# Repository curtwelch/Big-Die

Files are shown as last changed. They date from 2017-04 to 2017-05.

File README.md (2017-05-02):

# Readme

A Project to make a large 6" cube gambling die out of wood on a CNC router and out of plastic on a 3D Printer as a learning exercise.

Included here are the Fusion 360 CAD files, DXF files, and STL files.

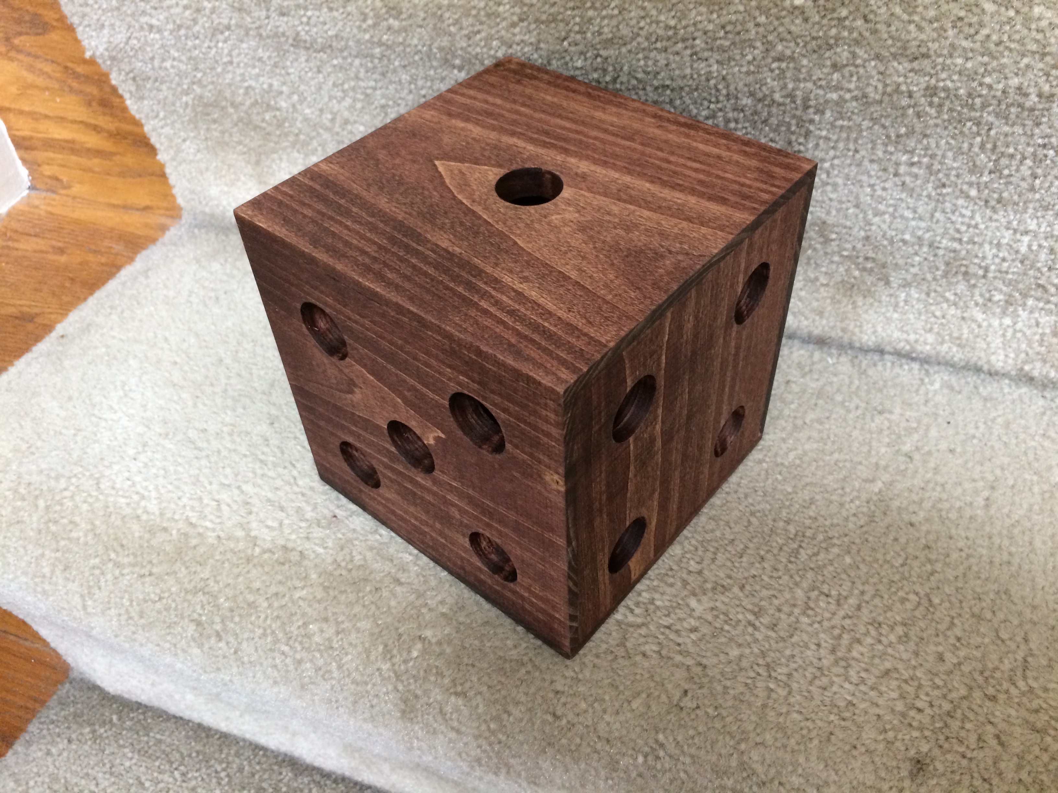
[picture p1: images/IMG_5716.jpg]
die


* <a href="die v7.dxf">die v7.dxf</a> -- 2D line drawing for use with CNC Router

* <a href="die v7.f3d">die v7.f3d</a> -- Autodesk Fusion 360 CAD source file

* <a href="die v7.stl">die v7.stl</a> -- 3D object file for 3D printing

* <a href="Wooden Die Drawing v3.pdf">Wooden Die Drawing v3.pdf</a> -- Mechanical Drawing of parts

* [images.md](images.md) -- Pictures

The Wooden faces were cut from 8"x1" (lumber dimensions) Poplar, planned down to the 1/2" thickness and then cut on a ShopSabre cnc router.  The "die v7.dxf" file here was used with the Vcarve Software to program the ShopSabre.

The resulting board was then cut apart; sanded; stained on the inside faces; glued together; sanded, stained, and waxed.

The small 3D Printer plastic cube was printed from the stl file here.  The parts were scaled to make the small parts and allow all 6 sides to be printed at once.  They were then glued together to create the cube.

Many thanks to everyone at http://nova-labs.org/ who helped me learn the technology and skills needed to do this work as well as assist in this project!  Support your local maker space!

Curt Welch<br>
curt@kcwc.com<br>
5-1-2017

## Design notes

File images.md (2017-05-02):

3D-Printing the small plastic version to verify geometry.
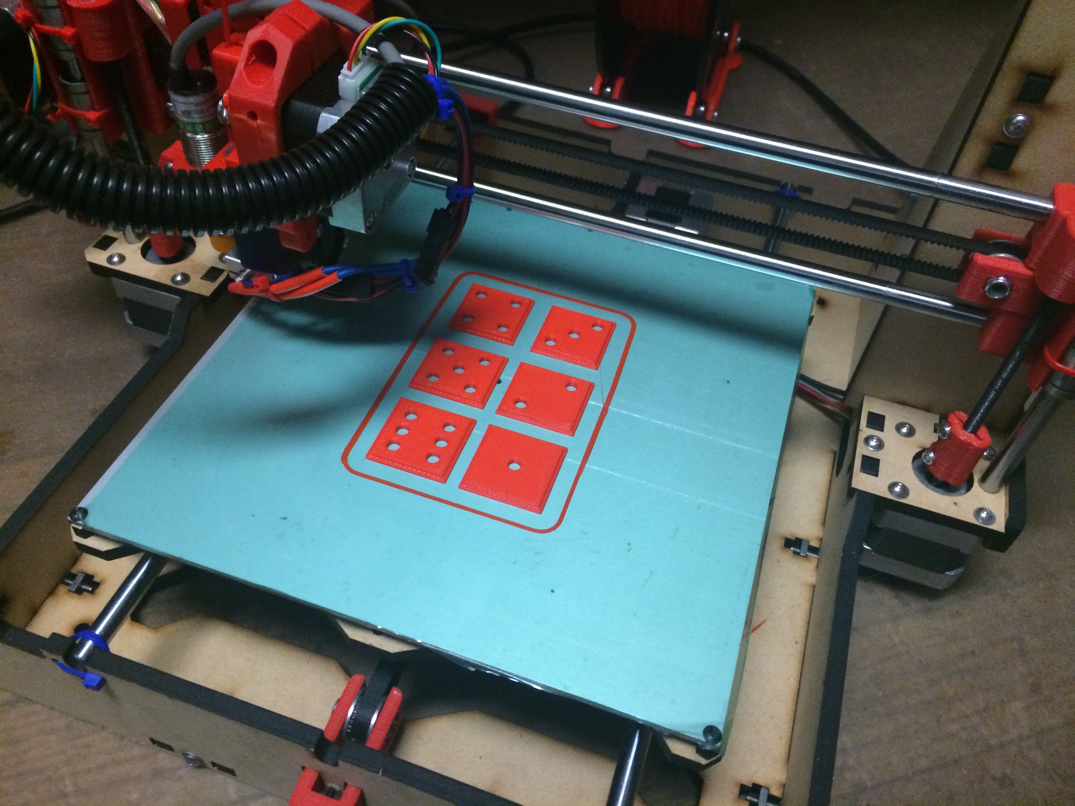
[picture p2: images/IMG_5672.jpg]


Finished CNC Router work, with an Aluminum version I made years ago, and the 3D printed plastic version for reference.
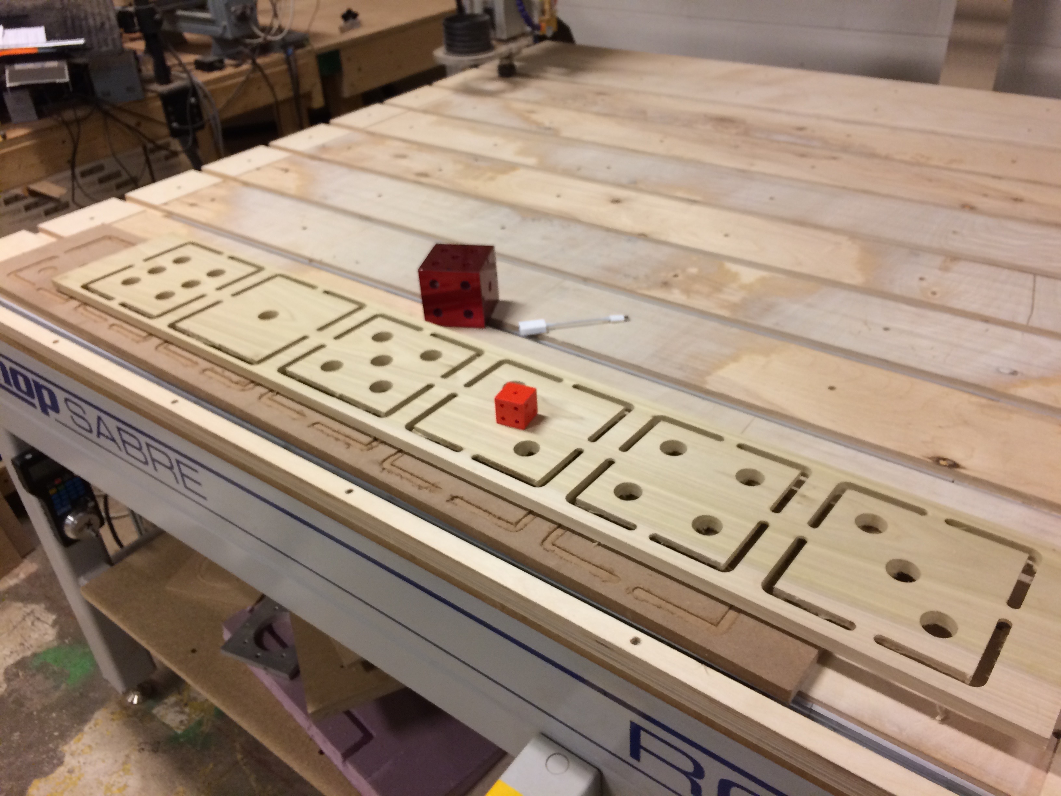
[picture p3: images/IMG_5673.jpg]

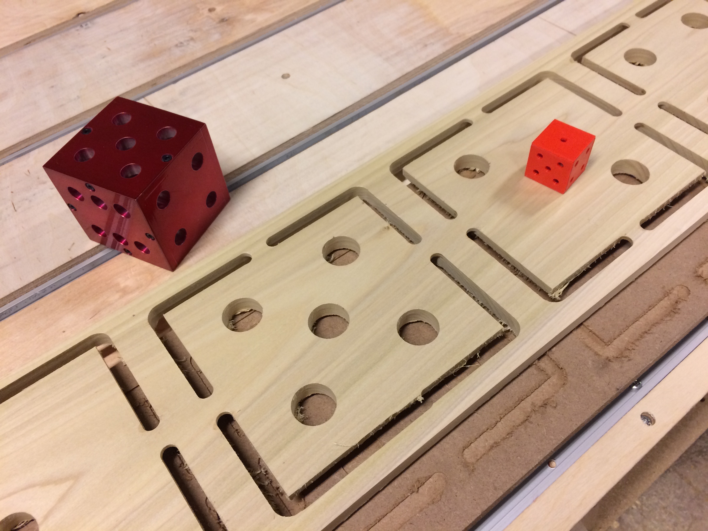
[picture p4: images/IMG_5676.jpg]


Cleaning up edges by hand.
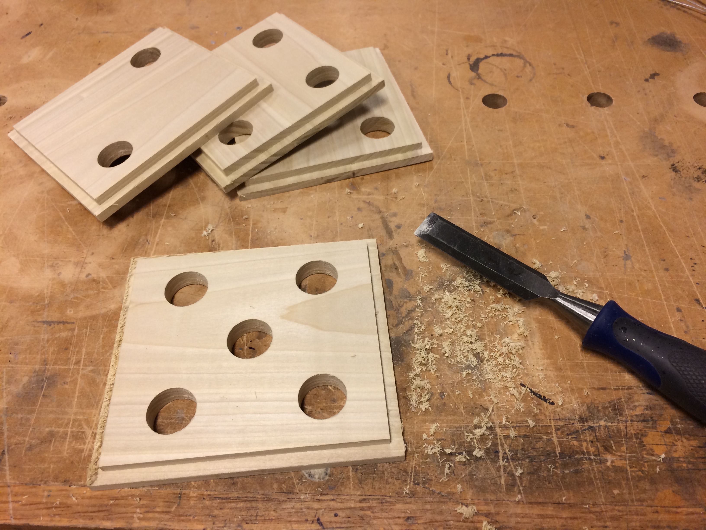
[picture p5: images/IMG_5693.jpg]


Staning and gluing.
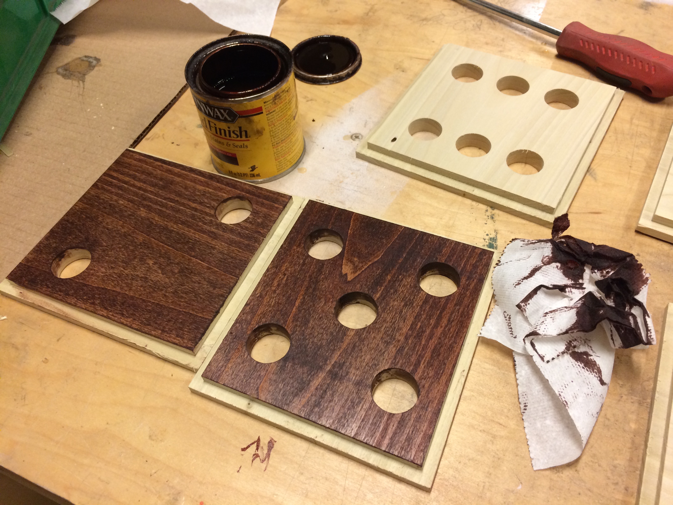
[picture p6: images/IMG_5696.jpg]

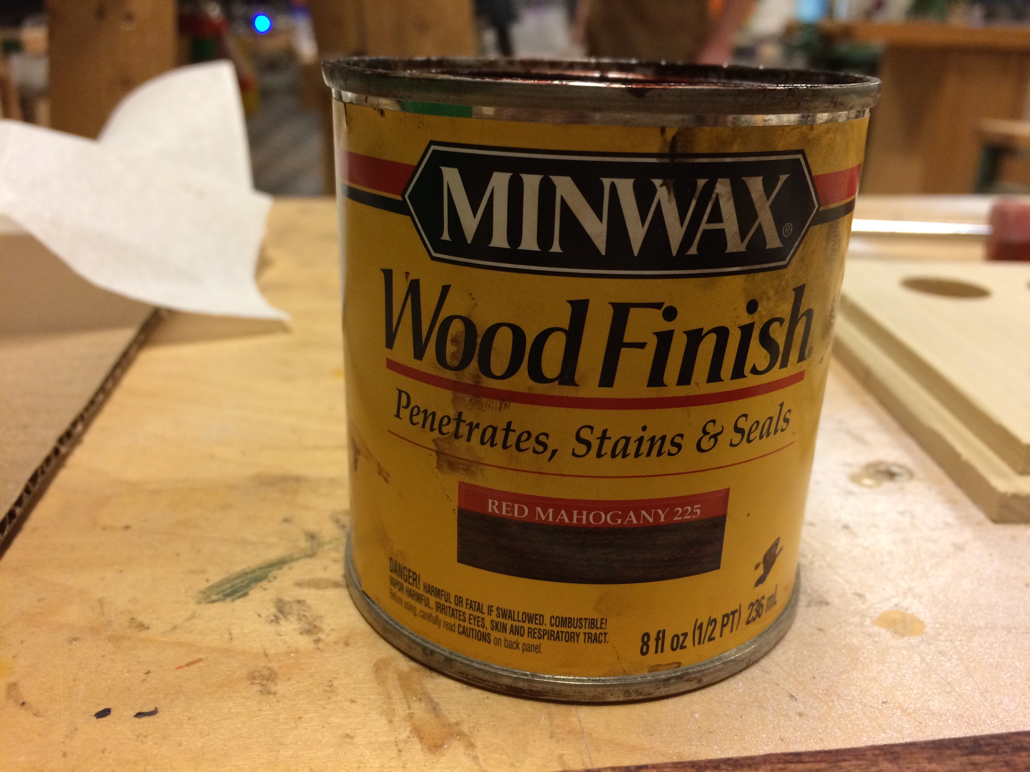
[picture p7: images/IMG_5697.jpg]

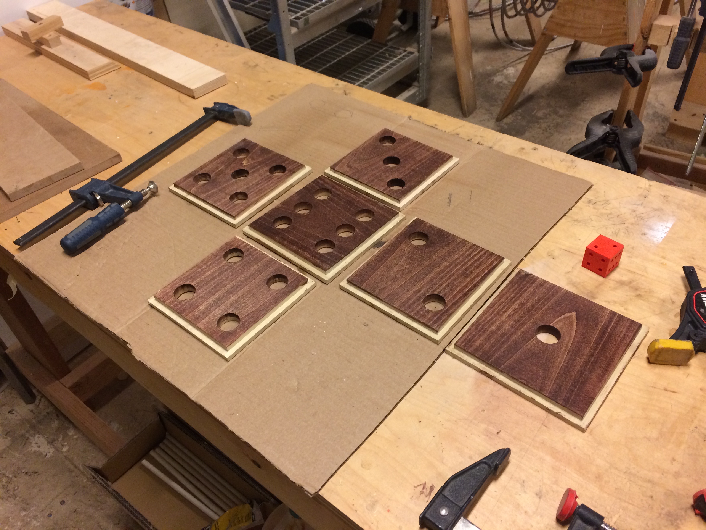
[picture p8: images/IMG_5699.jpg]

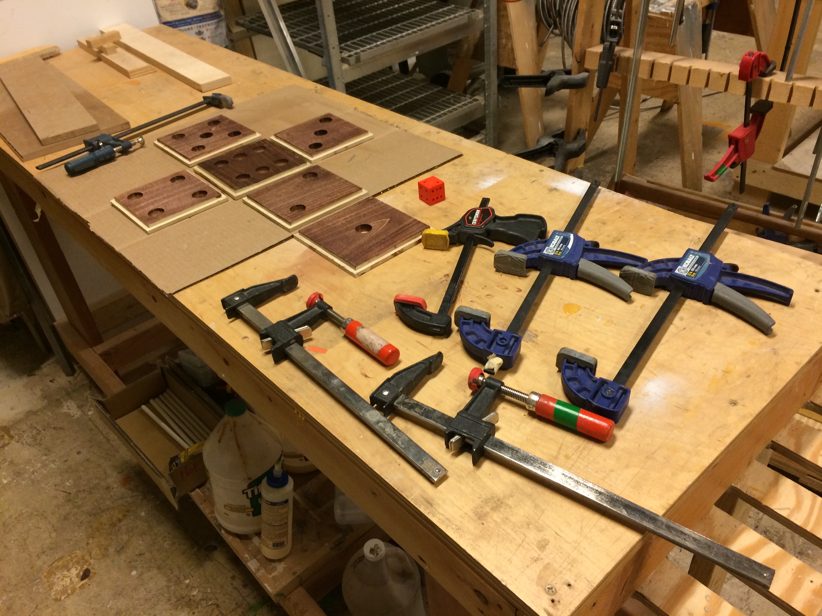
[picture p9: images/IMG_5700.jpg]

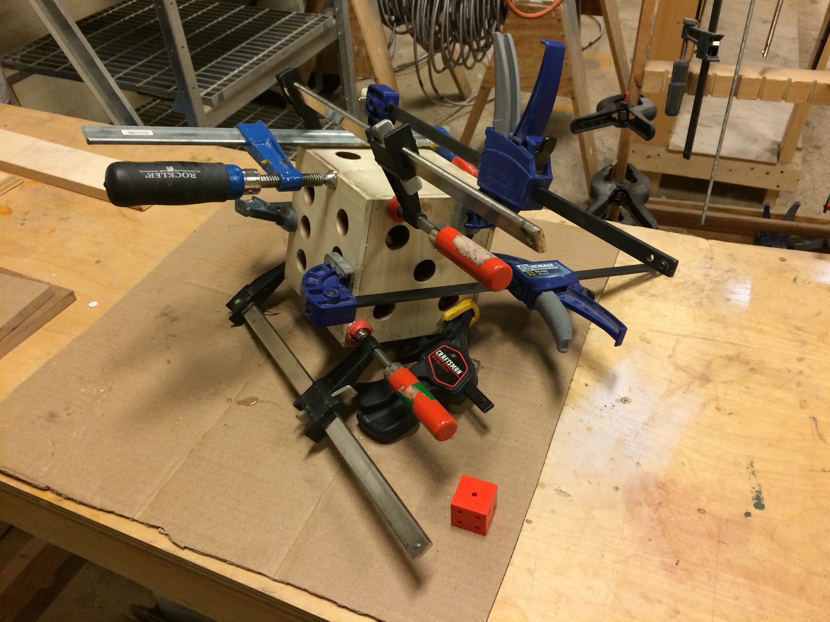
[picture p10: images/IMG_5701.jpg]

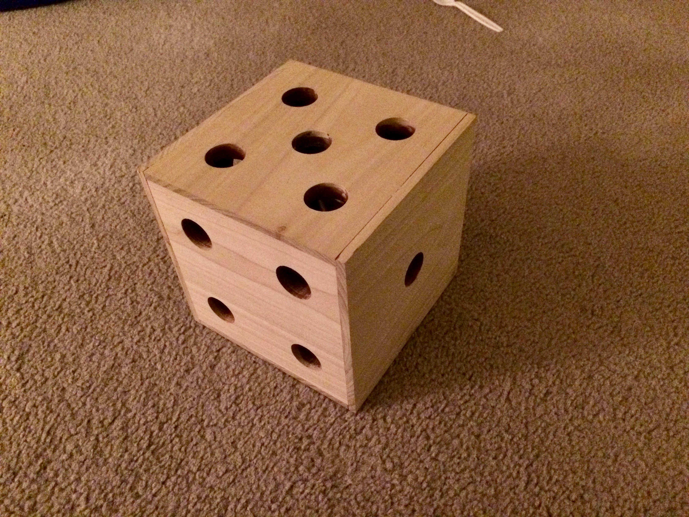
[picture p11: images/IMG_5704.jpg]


Finished version.


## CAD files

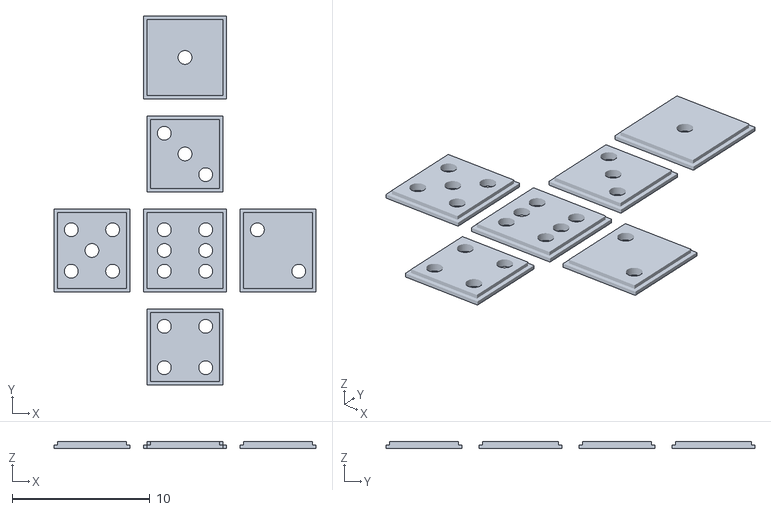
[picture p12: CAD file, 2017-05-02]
die v7.stl
19.0 x 26.8 x 0.5

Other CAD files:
die-1x6.dxf
die v7.dxf
die v7.f3d

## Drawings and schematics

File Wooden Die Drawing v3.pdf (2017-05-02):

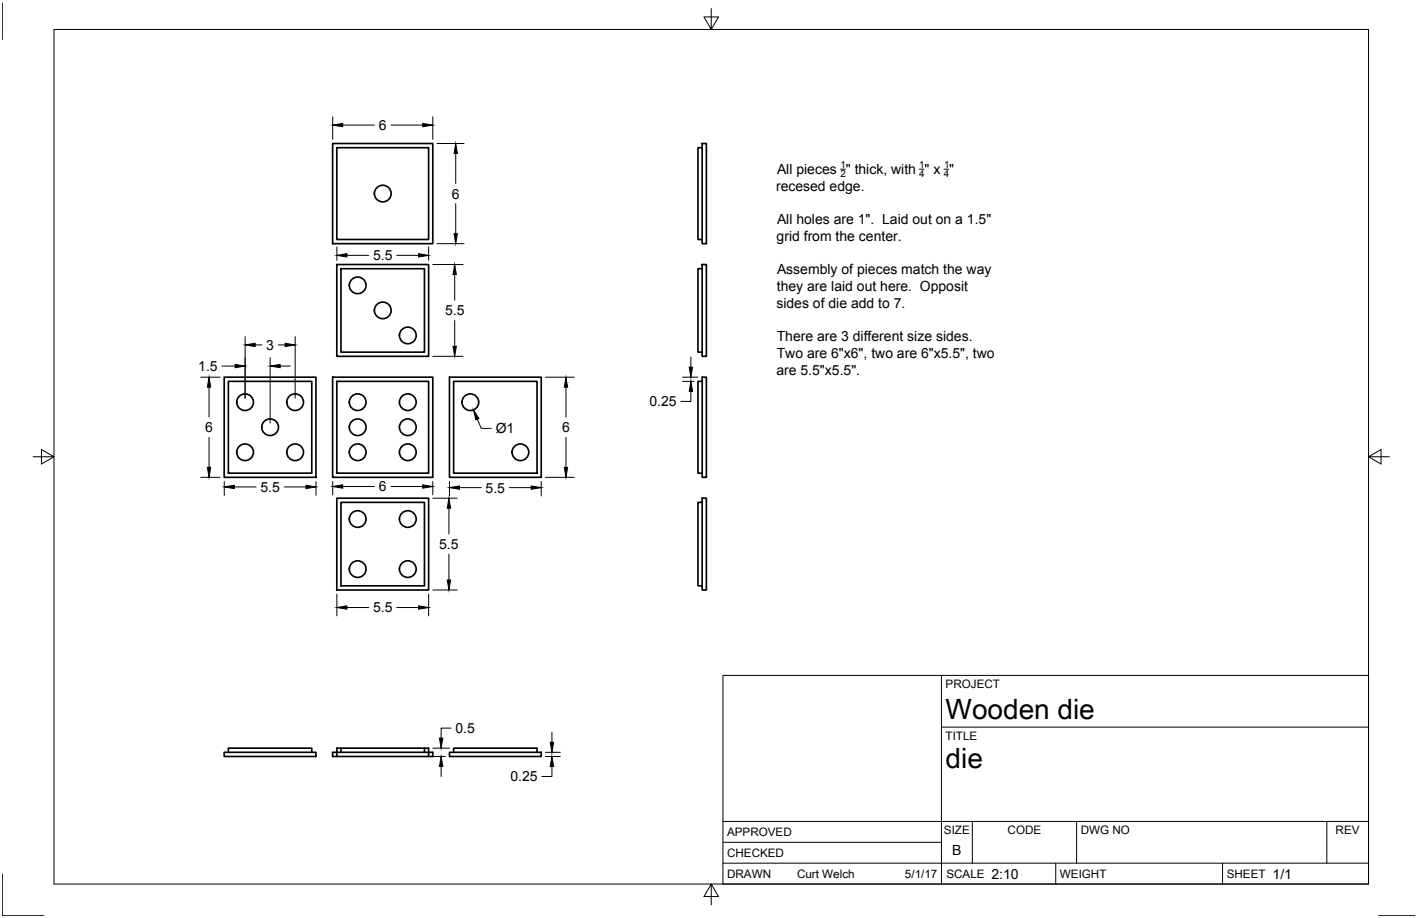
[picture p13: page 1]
SIZE; CODE; DWG NO; REV; Curt Welch; Wooden die; All pieces 1; " thick, with 1; recesed edge.

All holes are 1". Laid out on a 1.5"
grid from the center.

Assembly of pieces match the way
they are laid out here. Opposit
sides of die add to 7.

There are 3 different size sides.
Two are 6"x6", two are 6"x5.5", two
are 5.5"x5.5".

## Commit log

2017-04-25 Add first files
    [die v2.stl, die.dxf]
2017-04-27 Added pictures of Shop Sabre results
    [die-1x6.dxf, die-2x3.dxf]
2017-05-02 update finished files
    [die v2.stl, die v7.dxf, die v7.f3d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]
